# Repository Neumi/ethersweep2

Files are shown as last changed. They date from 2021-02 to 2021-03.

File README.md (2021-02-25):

# ethersweep
Ethernet + UDP + Json motor controller. Based on open source soft- and hardware.
Version2 has an built in AS5600 magnetic encoder for position feedback, the option for an END-stop for homing and an E-stop -just in case.
The controller uses 8.5V to 12V from a standard XT60 connector.
All built into a small form factor that fits on the backside of a NEMA 17 stepper motor.

## What it does
Ethersweep is a simple to use ethernet connected stepper motor driver. It lets you use JSON formatted string to controll stpper motors via Ethernet. 

## How to get started:
Connect ethersweep to your network via ethernet and to a +12v power source.
Once connected it serarches for an IP address on the network using DHCP. When an IP is found, the controller shows it on the display and its ready to use.

Now you can use the Python script to control the motor.

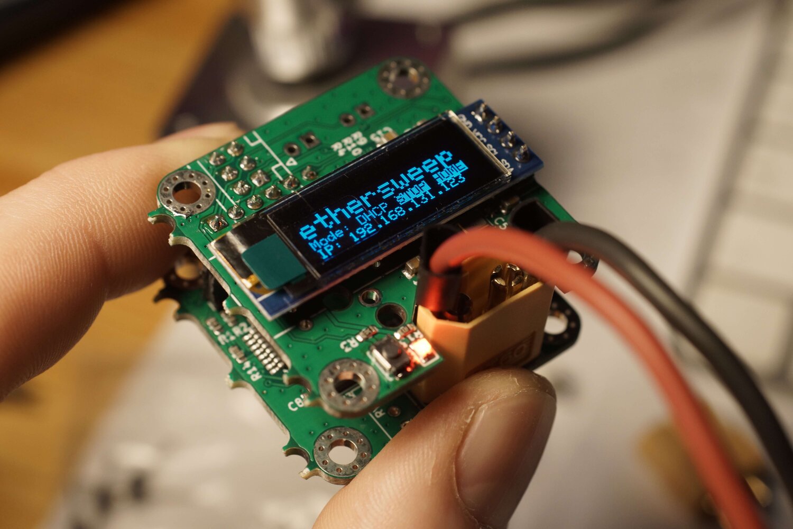
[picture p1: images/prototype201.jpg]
PCB Photo

PCB raw B
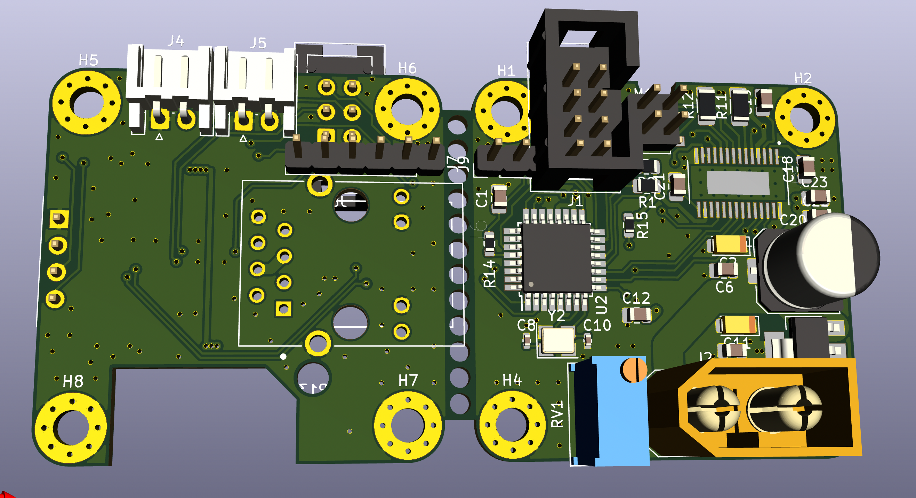
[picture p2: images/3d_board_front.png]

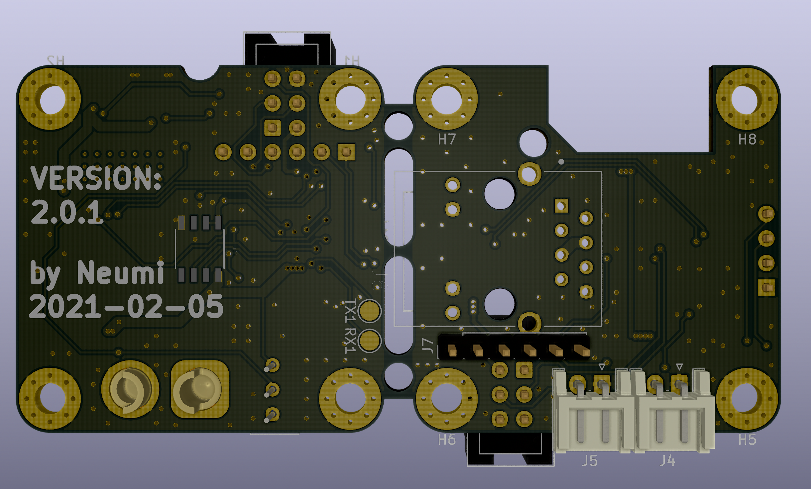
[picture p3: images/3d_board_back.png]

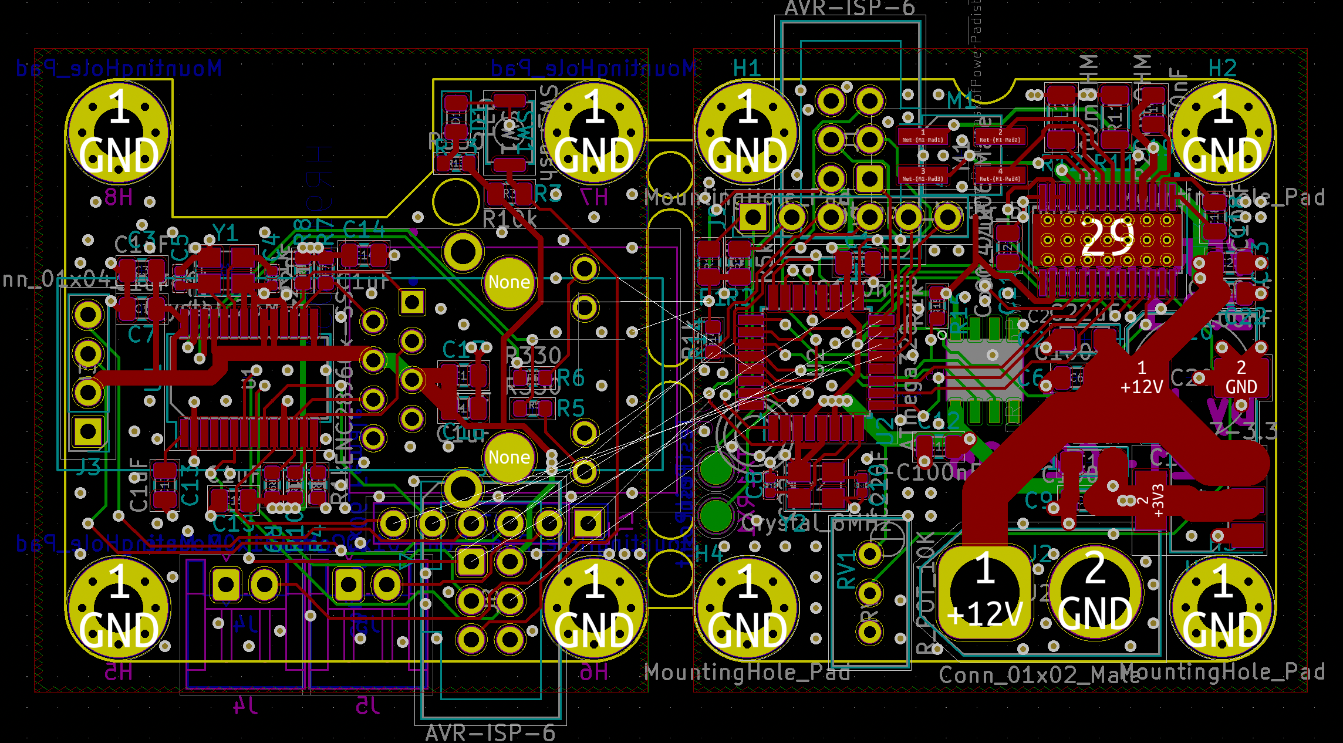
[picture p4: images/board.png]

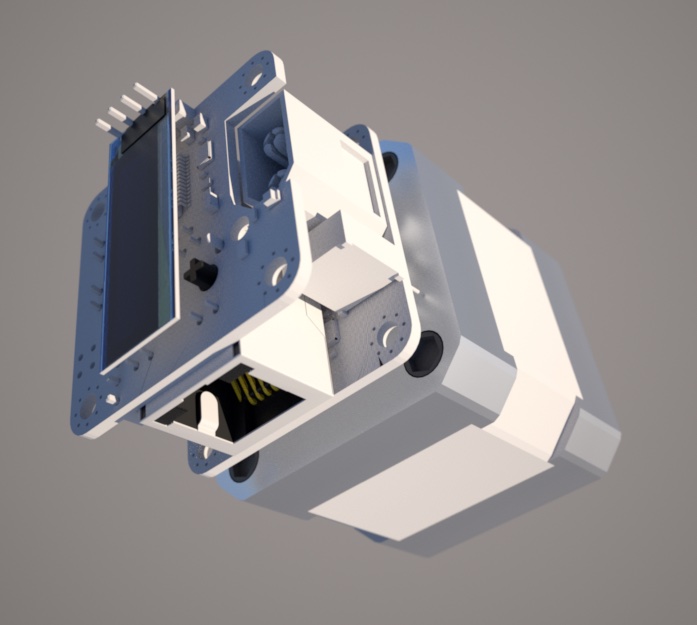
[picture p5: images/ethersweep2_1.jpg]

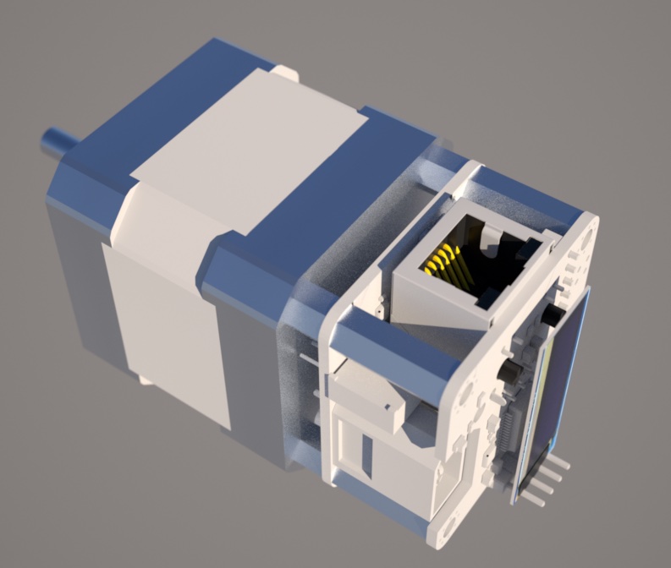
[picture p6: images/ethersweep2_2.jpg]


## Using Python to controll a stepper motor:

```python
import socket
import json

IP_MOTOR = "192.168.1.185" #local motor controller IP
UDP_PORT = 1337

def drive_motor(steps, speed, direction, stepmode, motor_ip):
    json_data = json.dumps({'steps': steps, 'speed': speed, 'direction': direction, 'stepmode': stepmode})
    message = json_data.encode()
    sock = socket.socket(socket.AF_INET, socket.SOCK_DGRAM)
    sock.sendto(message, (motor_ip, UDP_PORT))

drive_motor(100, 9500, 1, 32, IP_MOTOR)
```

## Video:
LINK TO VIDEO (https://www.youtube.com/watch?v=CZqzoTy67dk)

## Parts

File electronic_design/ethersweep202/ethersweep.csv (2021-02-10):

Comment | Designator | Footprint | LCSC Part Number
C100nF | C1,C6,C9,C12,C19,C22,C23 | Capacitor_SMD:C_0805_2012Metric | C49678
C1uF | C3,C7,C13,C14,C15,C16,C17 | Capacitor_SMD:C_0805_2012Metric | C28323
C10nF | C18 | Capacitor_SMD:C_0805_2012Metric | C1710
C4.7uF | C2,C11 | Capacitor_SMD:C_1206_3216Metric | C29823
C0.47uF | C21 | Capacitor_SMD:C_0805_2012Metric | C13967
C22pF | C4,C5,C8,C10 | Capacitor_SMD:C_0402_1005Metric | C1555
LED | D1 | LED_SMD:LED_0805_2012Metric | C84256
HR911105A | J6 | modules:HANRUN_HR911105A | C12074
R10k | R1,R2,R3 | Resistor_SMD:R_0603_1608Metric | C25804
R200mOHM | R11,R12 | Resistor_SMD:R_1206_3216Metric | C25335
R330 | R5,R6,R13 | Resistor_SMD:R_0603_1608Metric | C23138
R1k | R4,R7,R8,R9,R10,R14,R15 | Resistor_SMD:R_0603_1608Metric | C21190
R_POT_10K | RV1 | Potentiometer_THT:Potentiometer_Bourns_3296W_Vertical | C118954
ATmega328-AU | U2 | Package_QFP:TQFP-32_7x7mm_P0.8mm | C14877
DRV8825PWPR | U3 | modules:IC_TPS61196PWPRQ1 | C81582
AMS1117-3.3 | U4 | Package_TO_SOT_SMD:SOT-223-3_TabPin2 | C6186
Crystal_25MHz | Y1 | Crystal:Crystal_SMD_3225-4Pin_3.2x2.5mm | C9006
Crystal | Y3 | Crystal:Crystal_SMD_5032-2Pin_5.0x3.2mm | C115962

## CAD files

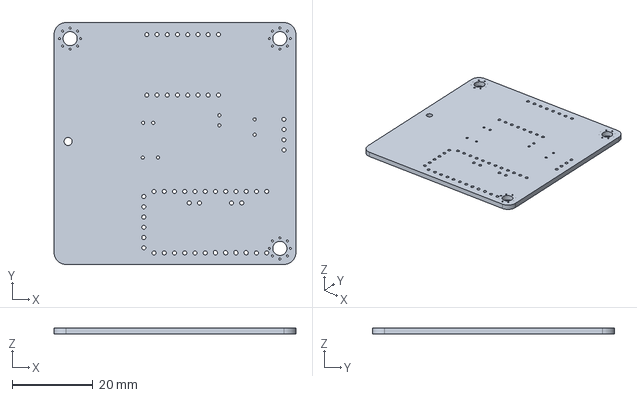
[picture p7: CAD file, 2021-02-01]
electronic_design/ethersweep2/ethersweep.step
60.0 x 60.0 x 1.60 mm

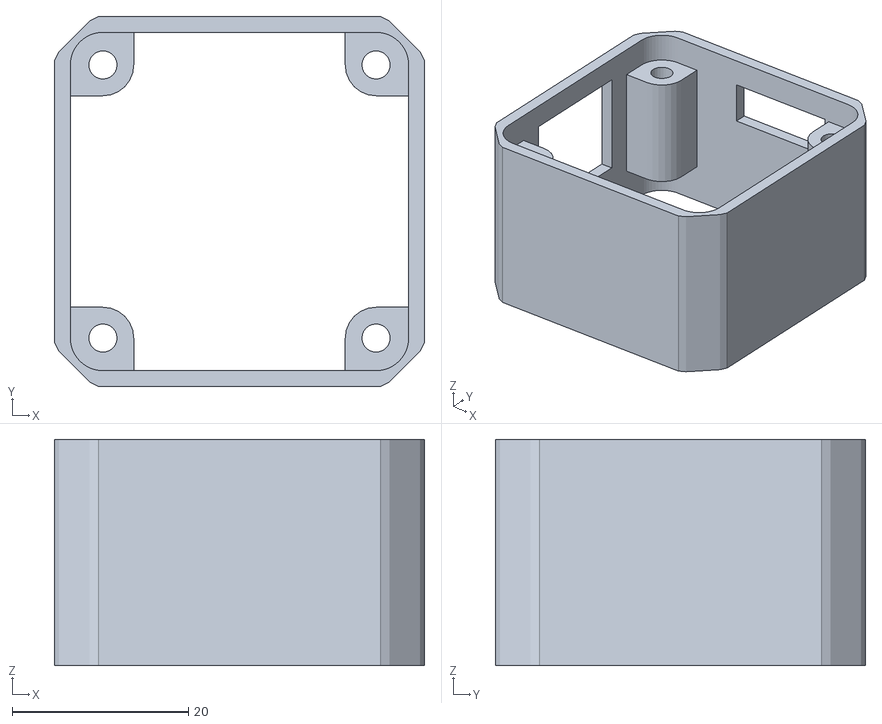
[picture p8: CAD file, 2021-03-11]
STL/ethersweep_case.stl
42.0 x 42.0 x 25.7

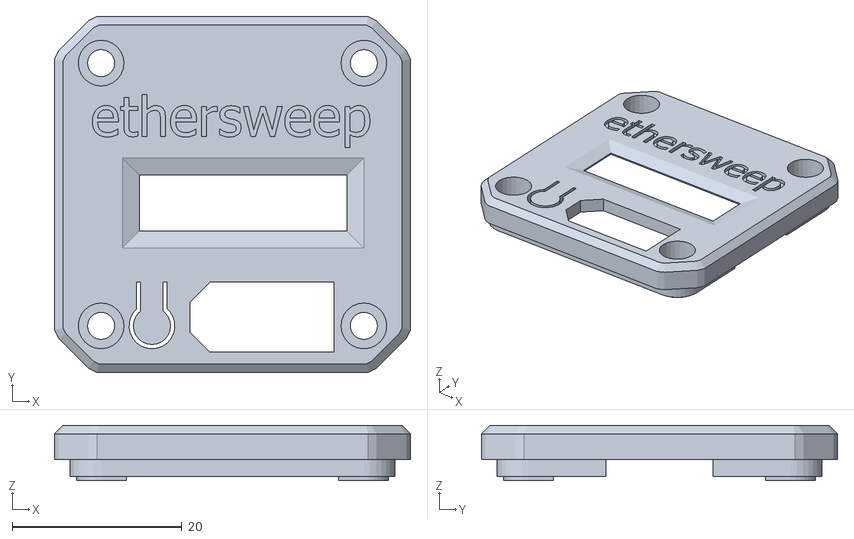
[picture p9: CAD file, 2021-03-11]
STL/ethersweep_top.stl
42.0 x 42.0 x 6.50

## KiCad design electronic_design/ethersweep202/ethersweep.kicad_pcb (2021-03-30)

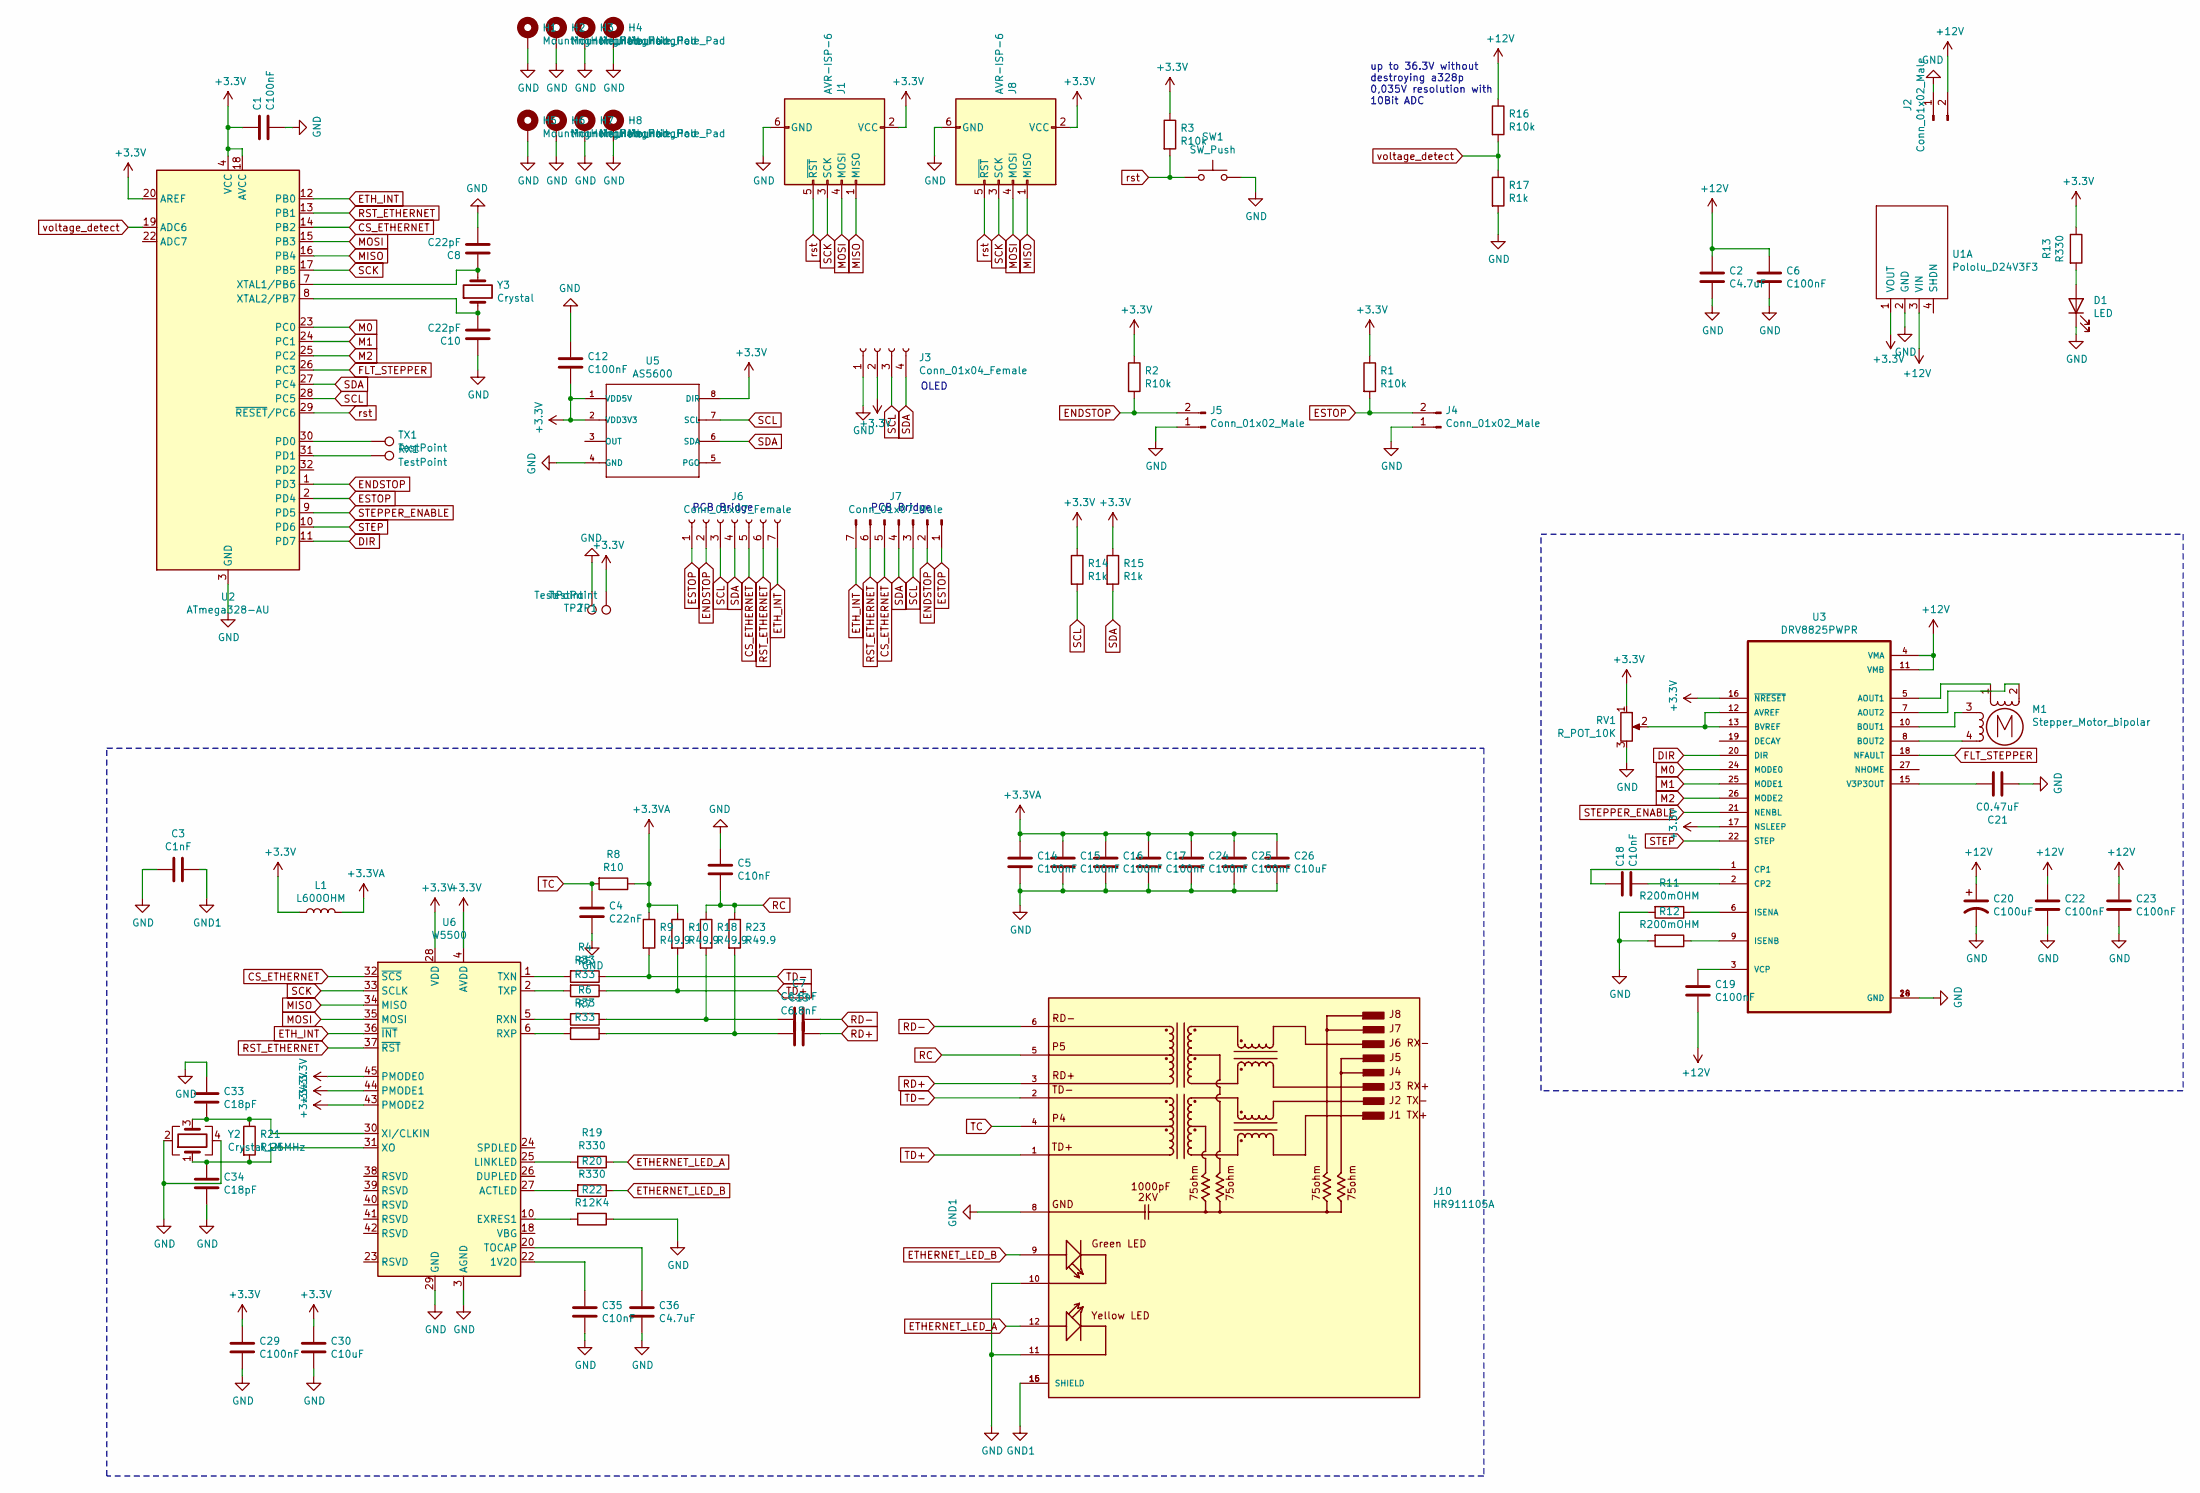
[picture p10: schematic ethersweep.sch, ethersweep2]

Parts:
C1, C6, C12, C19, C22, C23: C100nF; C_0805_2012Metric; LCSC C49678
C2: C4.7uF; C_1206_3216Metric; LCSC C29823
C3: C1nF; R_1206_3216Metric; LCSC C35216
C4: C22nF; R_0603_1608Metric; LCSC C21122
C5, C35: C10nF; C_0603_1608Metric; LCSC C57112
C7, C13: C6.8nF; R_0402_1005Metric; LCSC C1542
C8, C10: C22pF; C_0402_1005Metric; LCSC C1555
C14, C15, C16, C17, C24, C25, C29: C100nF; C_0402_1005Metric; LCSC C1525
C18: C10nF; C_0805_2012Metric; LCSC C1710
C20: C100uF; CP_Elec_8x10; LCSC C176665
C21: C0.47uF; C_0805_2012Metric; LCSC C13967
C26, C30: C10uF; C_0805_2012Metric; LCSC C15850
C33, C34: C18pF; C_0402_1005Metric; LCSC C1549
C36: C4.7uF; C_0402_1005Metric; LCSC C23733
D1: LED; LED_0805_2012Metric; LCSC C84256
H1, H2, H3, H4, H5, H6, H7, H8: MountingHole_Pad; MountingHole_3.2mm_M3_Pad_Via
J1, J8: AVR-ISP-6; IDC-Header_2x03_P2.54mm_Vertical
J2: Conn_01x02_Male; AMASS_XT30PW-M_1x02_P2.50mm_Horizontal
J3: Conn_01x04_Female; PinHeader_1x04_P2.54mm_Vertical
J4, J5: Conn_01x02_Male; JST_EH_S2B-EH_1x02_P2.50mm_Horizontal
J6: Conn_01x07_Female; PinHeader_1x07_P2.54mm_Vertical
J7: Conn_01x07_Male; PinHeader_1x07_P2.54mm_Vertical
J10: HR911105A; HANRUN_HR911105A; PARTREV A; LCSC C12074
L1: L600OHM; L_0805_2012Metric; LCSC C1017
M1: Stepper_Motor_bipolar; PinHeader_2x02_P2.54mm_Vertical_SMD
R1, R2, R3: R10k; R_0603_1608Metric; LCSC C25804
R4, R5, R6, R7: R33; R_0805_2012Metric; LCSC C17634
R8: R10; R_0805_2012Metric; LCSC C17415
R9, R10, R18, R23: R49.9; R_0603_1608Metric; LCSC C23185
R11, R12: R200mOHM; R_1206_3216Metric; LCSC C25335
R13, R19, R20: R330; R_0603_1608Metric; LCSC C23138
R14, R15: R1k; R_0603_1608Metric; LCSC C21190
R16: R10k; R_0603_1608Metric
R17: R1k; R_0603_1608Metric
R21: R1M; R_0805_2012Metric; LCSC C17514
R22: R12K4; R_0805_2012Metric; LCSC C30908
RV1: R_POT_10K; Potentiometer_Bourns_3296W_Vertical; LCSC C118954
RX1: TestPoint; TestPoint_Pad_D2.0mm
SW1: SW_Push; SW_Push_SPST_NO_Alps_SKRK
TP1, TP2: TestPoint; TestPoint_Pad_D2.0mm
TX1: TestPoint; TestPoint_Pad_D2.0mm
U1: Pololu_D24V3F3
U2: ATmega328-AU; TQFP-32_7x7mm_P0.8mm; LCSC C14877
U3: DRV8825PWPR; IC_TPS61196PWPRQ1; LCSC C81582
U5: AS5600
U6: W5500; LQFP-48_7x7mm_P0.5mm
Y2: Crystal_25MHz; Crystal_SMD_3225-4Pin_3.2x2.5mm; LCSC C9006
Y3: Crystal; Crystal_SMD_5032-2Pin_5.0x3.2mm; LCSC C115962

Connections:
+12V: C2.1, C6.1, C19.2, C20.1, C22.1, C23.1, J2.2, R16.1, U1.3 (VIN), U3.4 (VMA), U3.11 (VMB)
CS_ETHERNET: J6.5, J7.5, U2.14 (PB2), U6.32 (~SCS)
DIR: U2.11 (PD7), U3.20 (DIR)
ENDSTOP: J5.2, J6.2, J7.2, R2.2, U2.1 (PD3)
ESTOP: J4.2, J6.1, J7.1, R1.2, U2.2 (PD4)
ETHERNET_LED_A: J10.12, R19.1
ETHERNET_LED_B: J10.9, R20.1
ETH_INT: J6.7, J7.7, U2.12 (PB0), U6.36 (~INT)
FLT_STEPPER: U2.26 (PC3), U3.18 (NFAULT)
GND: C1.2, C2.2, C3.2, C4.1, C5.1, C6.2, C8.2, C10.1, C12.1, C14.2, C15.2, C16.2, C17.2, C20.2, C21.2, C22.2, C23.2, C24.2, C25.2, C26.2, C29.2, C30.2, C33.1, C34.2, C35.2, C36.2, D1.1 (K), H1.1, H2.1, H3.1, H4.1, H5.1, H6.1, H7.1, H8.1, J1.6 (GND), J2.1, J3.1, J4.1, J5.1, J8.6 (GND), J10.10, J10.11, R11.2, R12.2, R17.2, R22.1, RV1.3, SW1.2, TP2.1, U1.2 (GND), U2.3 (GND), U2.5 (GND), U2.21 (GND), U3.14 (GND), U3.28 (GND), U5.4 (GND), U6.3 (AGND), U6.9 (AGND), U6.14 (AGND), U6.16 (AGND), U6.19 (AGND), U6.29 (GND), U6.48 (AGND), Y2.2, Y2.4; also elsewhere on the board
GND1: C3.1, J10.8, J10.15 (SHIELD), J10.16 (SHIELD)
M0: U2.23 (PC0), U3.24 (MODE0)
M1: U2.24 (PC1), U3.25 (MODE1)
M2: U2.25 (PC2), U3.26 (MODE2)
MISO: J1.1 (MISO), J8.1 (MISO), U2.16 (PB4), U6.34 (MISO)
MOSI: J1.4 (MOSI), J8.4 (MOSI), U2.15 (PB3), U6.35 (MOSI)
unnamed: C7.2, R6.1, R18.2
unnamed: C8.1, U2.7 (XTAL1/PB6), Y3.2
unnamed: C10.2, U2.8 (XTAL2/PB7), Y3.1
unnamed: C13.2, R7.1, R23.2
unnamed: C18.1, U3.1 (CP1)
unnamed: C18.2, U3.2 (CP2)
unnamed: C19.1, U3.3 (VCP)
unnamed: C21.1, U3.15 (V3P3OUT)
unnamed: C33.2, R21.1, U6.30 (XI/CLKIN), Y2.3
unnamed: C34.1, R21.2, U6.31 (XO), Y2.1
unnamed: C35.1, U6.22 (1V2O)
unnamed: C36.1, U6.20 (TOCAP)
unnamed: D1.2 (A), R13.2
unnamed: M1.1, U3.5 (AOUT1)
unnamed: M1.2 (-), U3.7 (AOUT2)
unnamed: M1.3, U3.10 (BOUT1)
unnamed: M1.4, U3.8 (BOUT2)
unnamed: R4.2, U6.1 (TXN)
unnamed: R5.2, U6.2 (TXP)
unnamed: R6.2, U6.5 (RXN)
unnamed: R7.2, U6.6 (RXP)
unnamed: R11.1, U3.6 (ISENA)
unnamed: R12.1, U3.9 (ISENB)
unnamed: R19.2, U6.25 (LINKLED)
unnamed: R20.2, U6.27 (ACTLED)
unnamed: R22.2, U6.10 (EXRES1)
unnamed 43: U2.32 (PD2); also elsewhere on the board
unnamed: RV1.2, U3.12 (AVREF), U3.13 (BVREF)
unnamed: RX1.1, U2.31 (PD1)
unnamed: TX1.1, U2.30 (PD0)
RC: C5.2, J10.5, R18.1, R23.1
RD+: C13.1, J10.3
RD-: C7.1, J10.6
RST_ETHERNET: J6.6, J7.6, U2.13 (PB1), U6.37 (~RST)
SCK: J1.3 (SCK), J8.3 (SCK), U2.17 (PB5), U6.33 (SCLK)
SCL: J3.3, J6.3, J7.3, R14.2, U2.28 (PC5), U5.7 (SCL)
SDA: J3.4, J6.4, J7.4, R15.2, U2.27 (PC4), U5.6 (SDA)
STEP: U2.10 (PD6), U3.22 (STEP)
STEPPER_ENABLE: U2.9 (PD5), U3.21 (NENBL)
TC: C4.2, J10.4, R8.2
TD+: J10.1, R5.1, R10.2
TD-: J10.2, R4.1, R9.2
rst: J1.5 (~RST), J8.5 (~RST), R3.2, SW1.1, U2.29 (~RESET~/PC6)
voltage_detect: R16.2, R17.1, U2.19 (ADC6)

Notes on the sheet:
up to 36.3V without destroying a328p 0,035V resolution with 10Bit ADC
OLED
PCB Bridge

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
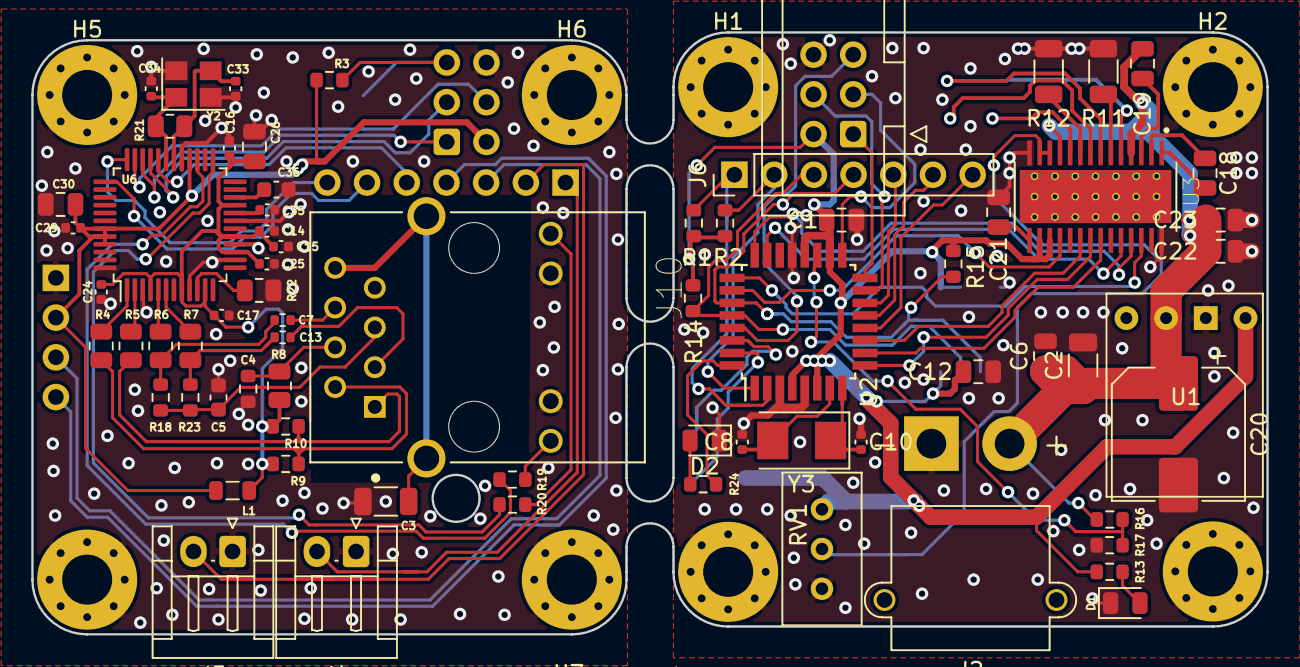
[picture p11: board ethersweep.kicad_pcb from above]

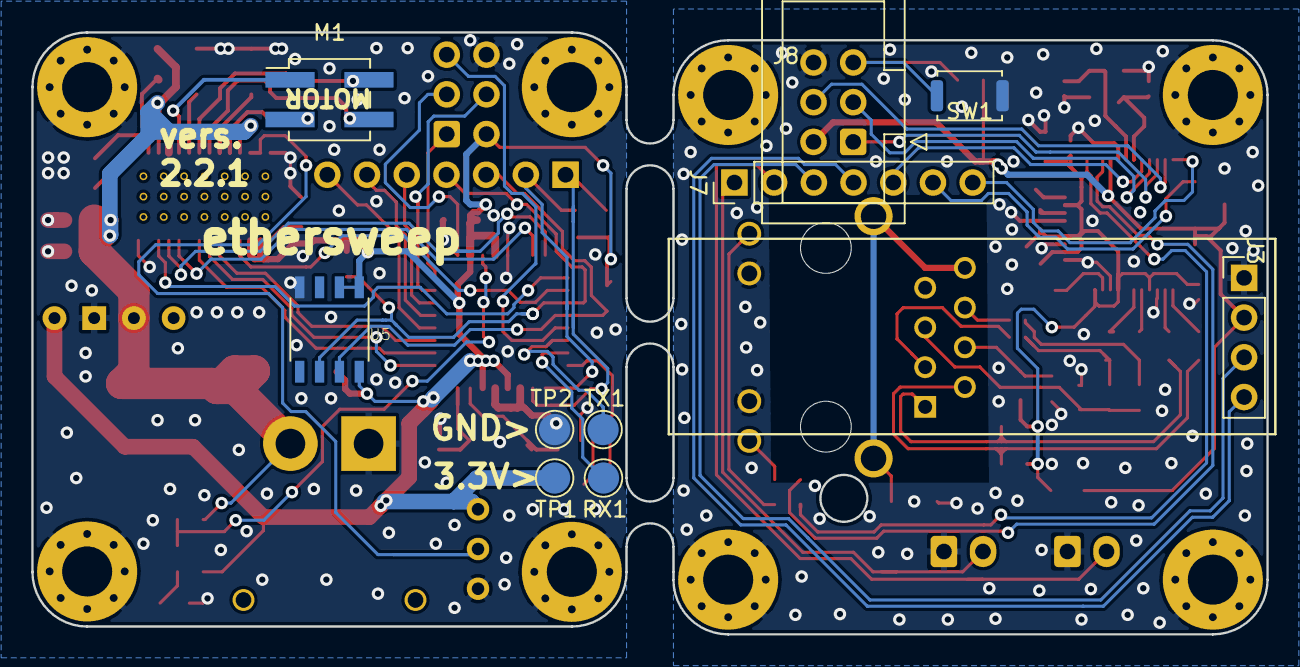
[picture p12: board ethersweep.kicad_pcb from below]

Board: 2 copper layers, 79.0 x 38.5 mm, 88 parts (10 on the bottom side), 63 nets.

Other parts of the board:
D2: LED; LED_0805_2012Metric
R24: R330; R_0603_1608Metric

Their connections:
GND: D2.1; also elsewhere on the board
unnamed: D2.2, R24.2
unnamed 43: R24.1; also elsewhere on the board

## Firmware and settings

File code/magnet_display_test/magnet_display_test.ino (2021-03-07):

#include <IPAddress.h>
#include <Adafruit_NeoPixel.h>
#include "SSD1306Ascii.h"
#include "SSD1306AsciiAvrI2c.h"
#include <Wire.h>
#include <AS5600.h>
#define SYS_VOL   3.3

AMS_5600 ams5600;

int ang = 0;
int lang = 0;

int stepPin = 6;
int dirPin = 5;
int enablePin = 7;
int sleepPin = 8;
int resetPin = 9;

int m0Pin = A3;
int m1Pin = A2;
int m2Pin = A1;
int faultPin = A0;
int voltDetectPin = A7;

int motorSpeed = 0;
int motorSteps = 0;
int motorDirection = 0;
int motorStepMode = 0;

boolean jobDone = true;
String ip_mode = "DHCP";

#define I2C_ADDRESS 0x3C
SSD1306AsciiAvrI2c oled;


static byte myip[] = { 192, 168, 1, 110 };


int estopPin = 4;
boolean eStopState = false;
int homePin = 3;
boolean homeState = false;

String lastIp;
boolean lastDhcp;
boolean lastStop;
boolean lastHome;

void setup() {
  oled.begin(&Adafruit128x32, I2C_ADDRESS);
  oled.setI2cClock(400000L); // 400khz for oled
  oled.displayRemap(true);
  oled.setFont(Adafruit5x7);

  oled.set2X();

  if (ams5600.detectMagnet() == 0 ) {
    while (1) {
      if (ams5600.detectMagnet() == 1 ) {

        drawDisplayMagnet("Mgntude: " + ams5600.getMagnitude());
        break;
      }
      else {
        drawDisplayMagnet("NO MAGNET");
      }
      delay(1000);
    }
  }





}

void loop() {
  eStopState = digitalRead(estopPin);
  homeState = digitalRead(homePin);

  drawDisplayState("192.168.131.123", true, eStopState, homeState);


  drawDisplayMagnet("Angle: " + String(convertRawAngleToDegrees(ams5600.getRawAngle()), DEC));



  /*
    drawDisplayState("192.168.131.123", false, true, true);
    delay(1000);

    drawDisplayState("192.168.131.123", true, true, true);
    delay(1000);

    drawDisplayState("192.168.131.123", true, false, true);
    delay(1000);

    drawDisplayState("192.168.131.123", false, false, false);
    delay(1000);
  */
}

float convertRawAngleToDegrees(word newAngle)
{
  /* Raw data reports 0 - 4095 segments, which is 0.087 of a degree */
  float retVal = newAngle * 0.087;
  ang = retVal;
  return ang;
}


void drawDisplayIp(String ip) {
  oled.setFont(Adafruit5x7);
  oled.clear();
  oled.set2X();
  oled.println("ethersweep");
  oled.set1X();
  oled.print("Mode: ");
  oled.println(ip_mode);
  oled.print("IP: ");
  oled.print(ip);
}

void drawDisplayState(String ip, boolean dhcp, boolean stop, boolean home) {
  if (lastIp == ip) {
    if (lastDhcp == dhcp) {
      if (lastStop == stop) {
        if (lastHome == home) {
          return;
        }
      }
    }
  }

  oled.setFont(Adafruit5x7);
  oled.set2X();
  oled.clear();
  oled.println("ethersweep");
  oled.set1X();
  oled.print("Mode: ");
  if (dhcp == true) {
    oled.print("DHCP ");
  } else {
    oled.print("STAT ");
  }
  if (stop == true) {
    oled.setInvertMode(true);
  }
  oled.print("STOP");
  oled.setInvertMode(false);
  oled.print(" ");
  if (home == true) {
    oled.setInvertMode(true);
  }
  oled.print("HOME");
  oled.setInvertMode(false);


  oled.println();
  oled.print("IP: ");
  oled.print(ip);

  lastIp = ip;
  lastDhcp = dhcp;
  lastStop = stop;
  lastHome = home;
}

void drawDisplayMagnet(String message) {
  oled.setFont(Adafruit5x7);
  oled.clear();
  oled.set2X();
  oled.println("ethersweep");
  oled.set1X();
  
  oled.print("Msg: ");
  oled.println(message);

}

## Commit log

2021-02-01 added new 2.0 design files
    [ethersweep.kicad_pcb, ethersweep.sch, ethersweep.step]
2021-02-01 raw component layout done
    [ethersweep.kicad_pcb, ethersweep.sch]
2021-02-01 board layout and routing for 1st board done
    [ethersweep.kicad_pcb, ethersweep.sch]
2021-02-01 board layouts done
    [ethersweep.kicad_pcb]
2021-02-03 board layout changed for single-piece manufacturing
    [ethersweep.kicad_pcb]
2021-02-03 small via fix
    [ethersweep.kicad_pcb]
2021-02-04 design improvements and error fixes
    [ethersweep.kicad_pcb, ethersweep.sch]
2021-02-05 changed images
    [ethersweep.kicad_pcb]
2021-02-08 added prod files
    [ethersweep-B_CrtYd.gbr, ethersweep-B_Cu.gbr, ethersweep-B_Fab.gbr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]
2021-02-09 changed resistor footprints from 805 to 603
2021-02-10 small routing changes
    [ethersweep.kicad_pcb]
2021-02-10 added LCSC part numbers and changed some components for cheap manufacturing
    [ethersweep.kicad_pcb, ethersweep.sch]
2021-02-10 footprint changes, LCSC parts assigned, design changes
    [ethersweep.kicad_pcb]
2021-02-10 design cleanup
    [ethersweep.kicad_pcb]
2021-02-10 added production files, BOM and POS files with JLCPCB part numbers and orientations
    [ethersweep-B_CrtYd.gbr, ethersweep-B_Cu.gbr, ethersweep-B_Fab.gbr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]
2021-02-11 minor changes
    [ethersweep.kicad_pcb]
2021-02-16 added hirachical sheets, changed page footers
    [atmega328_3_3V.sch, drv8825_stepper_motor_controller.sch, enc28j60_ethernet_controller.sch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]
2021-02-19 started cersion 2.0.2 with voltage detect
    [atmega328_3_3V.sch, drv8825_stepper_motor_controller.sch, enc28j60_ethernet_controller.sch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]
2021-02-22 minor v202 changes
    [ethersweep.kicad_pcb, ethersweep.sch]
2021-02-25 reversed xt60 polarity
    [ethersweep.kicad_pcb]
2021-02-25 added photo
    [ethersweep.sch]
2021-02-26 minor design changes and fixes
    [enc28j60_ethernet_controller.sch, ethersweep.kicad_pcb, ethersweep.sch]
2021-03-03 schematic changes
    [ethersweep.sch]
2021-03-03 layout refresh
    [ethersweep.kicad_pcb]
2021-03-05 202 design changed to w5500 ethernet driver
    [ethersweep.kicad_pcb, ethersweep.sch]
2021-03-05 added interrupt pin to w5500
    [ethersweep.sch]
2021-03-05 layout implementation board 1 done, board 2 in progress
    [ethersweep.kicad_pcb, ethersweep.sch]
2021-03-07 e-design changes
    [ethersweep.kicad_pcb]
2021-03-07 added stl files
    [ethersweep_bottom.stl, ethersweep_top.stl]
2021-03-10 design and layout changes
    [ethersweep.kicad_pcb, ethersweep.sch]
2021-03-11 new case and top files
    [ethersweep_bottom.stl, ethersweep_case.stl, ethersweep_top.stl]
2021-03-11 added full assembly STL
2021-03-11 added boards
2021-03-11 added screws
2021-03-24 major power supply canges
    [ethersweep.kicad_pcb, ethersweep.sch]
2021-03-26 layout changes, added status led ...
    [ethersweep.kicad_pcb, ethersweep.sch]
2021-03-29 layout changes
    [ethersweep.kicad_pcb]
2021-03-30 layout done. EMI improvements
    [ethersweep.kicad_pcb]
